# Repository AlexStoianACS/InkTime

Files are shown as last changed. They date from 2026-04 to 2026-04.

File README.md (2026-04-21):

## InkTime

Smartwatch ieftin si open source.

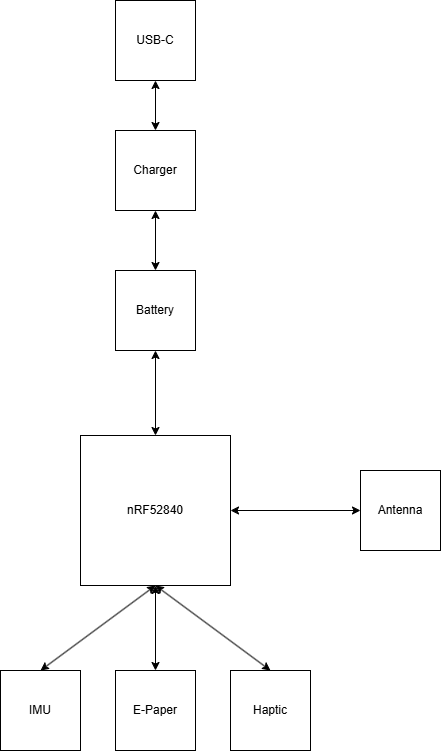
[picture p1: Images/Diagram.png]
Diagrama bloc


### Power Management

Charger LiPo: BQ25180

Regulator 3.3V: RT6160

Fuel gauge: MAX17048

#### Interfata

I2C (SDA/SCL bus comun)

Pini INT pentru evenimente (PMIC_INT, ALERT)

### Display (e-paper)

Conector FPC pentru display e-paper

Circuit de drive + PFET pentru power gating (VEPD)

#### Interfata

SPI:

SCK -> P0.02

MOSI -> P0.03

CS -> P0.05

Control:

DC -> P0.15

RST -> P0.16

BUSY -> P0.17

### Senzori

IMU (accelerometru): BMA421

#### Interfata

I2C:

SDA -> P0.06

SCL -> P0.07

### Haptic Feedback

DRV2605L

#### Interfata

I2C (bus comun)

Enable:

HAPTIC_EN -> P0.12

### Butoane

Up -> P0.13

Down -> P0.14

Enter -> P1.00

### Interfata
D+ -> USB DP (nRF52840)

D- -> USB DM (nRF52840)

VBUS -> detect pin

### Schematic

Schematicul l-am realizat pe o singura pagina.

Toate rezistentele sunt SMD, in capsula 0201. Toate condensatoarele sunt SMD, cele cu valori mai mici sau egale cu 100nF sunt in capsula 0201, cele cu valori mai mari de 100nF sunt 0402.

Am ignorat erorile de ERC de genul "Power pin X connected to Y" sau "Only one pin on net X".

### PCB

PCB-ul este de tip 2-layer si am facut rutarea pe ambele parti, in timp ce componentele sunt doar pe top.

Am plasat butoanele, usb-c connector si e-paper display connector pentru a se alinia cu marginile corespunzator.

Condensatoarele de decuplare (100nF) au fost plasate cat mai aproape de pinii de alimentare. De asemenea, cristalele au fost plasate cat mai aproape de MCU.

Am izolat antena de restul circuitului, nu am trasat rute pe top / bottom unde se afla si nu am facut "polygon pour" in acea zona. Pad-ul "2" a fost plasat in exterior.

Rutele au grosimea 0.3mm pentru semnalele de tip "POWER" si 0.15mm in rest. In anumite cazuri am scazut grosimea pentru a le putea strecura prin anumite locuri.

M-am ajutat de "escape routing" prin plasarea unui via direct pe pin / pad si inceperea rutarii direct pe bottom.

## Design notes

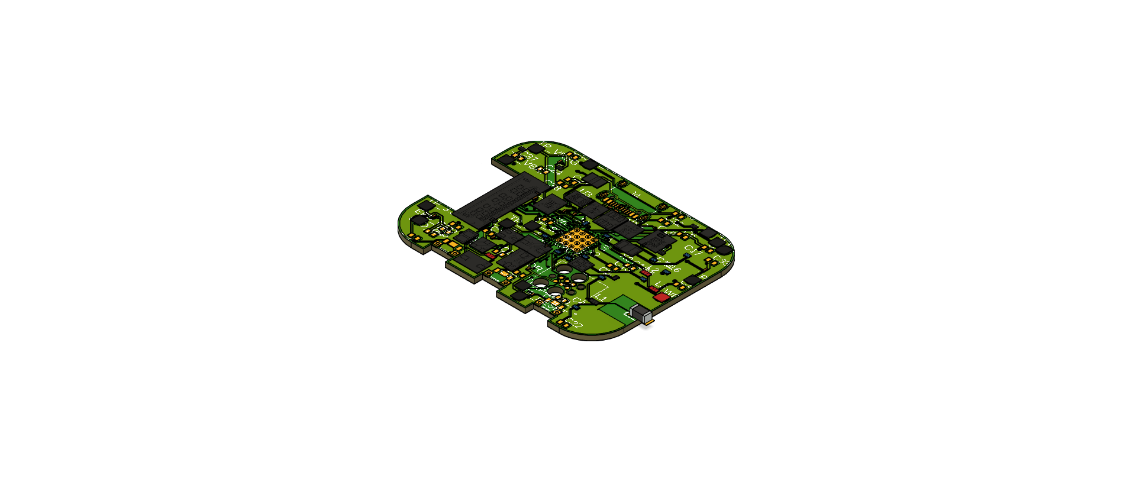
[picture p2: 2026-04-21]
Images/PCB.png

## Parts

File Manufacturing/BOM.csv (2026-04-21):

Reference Designators | Quantity | Description | Package | Value | Manufacturer | Manufacturer Part Number | Vendor | Vendor Part Number | Top/Bottom
 | 1 | Board | Board
ANT1 | 1 | Antennas 2.45GHz ANTENNA | 2450AT18B100E | 2450AT18B100E |  |  |  |  | Top
C1, C2, C17, C18 | 4 | Generic chip capacitor | NORDIC_NRF_3_RESC0201_L | 12pF |  |  |  |  | Top
C1-EP-DR, C24, C39 | 3 | CAPACITOR, European symbol | ESP32_C6_LIBRARY_1_ESP32_WROVER_EAGLE-LTSPICE_C0402 | 10uF |  |  |  |  | Top
C2-EP-DR, C6, C14, C20, C21, C43 | 6 | CAPACITOR, European symbol | ESP32_C6_LIBRARY_1_ESP32_WROVER_EAGLE-LTSPICE_C0402 | 4.7uF |  |  |  |  | Top
C3, C4 | 2 | Generic chip capacitor | NORDIC_NRF_3_RESC0201_L | 1pF |  |  |  |  | Top
C5, C7, C8, C12, C19 | 5 | Generic chip capacitor | NORDIC_NRF_3_RESC0201_L | 100nF |  |  |  |  | Top
C9 | 1 | Generic chip capacitor | NORDIC_NRF_3_RESC0201_L | 820pF |  |  |  |  | Top
C10, C13, C22 | 3 | CAPACITOR, European symbol | ESP32_C6_LIBRARY_1_ESP32_WROVER_EAGLE-LTSPICE_C0402 | N.C. |  |  |  |  | Top
C11 | 1 | Generic chip capacitor | NORDIC_NRF_3_RESC0201_L | 100pF |  |  |  |  | Top
C15 | 1 | CAPACITOR, European symbol | ESP32_C6_LIBRARY_1_ESP32_WROVER_EAGLE-LTSPICE_C0402 | 1.0uF |  |  |  |  | Top
C16 | 1 | Generic chip capacitor | NORDIC_NRF_3_RESC0201_L | 47nF |  |  |  |  | Top
C23, C27, C34, C42 | 4 | Check availability | CAPC0201X13N | 0.1uF |  |  |  |  | Top
C25, C33 | 2 | CAPACITOR, European symbol | ESP32_C6_LIBRARY_1_ESP32_WROVER_EAGLE-LTSPICE_C0402 | 22uF |  |  |  |  | Top
C29, C30, C31, C32, C37, C38 | 6 | CAPACITOR, European symbol | ESP32_C6_LIBRARY_1_ESP32_WROVER_EAGLE-LTSPICE_C0402 | 1uF |  |  |  |  | Top
D2, D4, D5 | 3 | ON SEMICONDUCTOR - MBR0530 - DIODE, SCHOTTKY, 0.5A, 30V, SOD-123 | SOD3716X135N | MBR0530 |  |  |  |  | Top
D3 | 1 | Low Cap. ESD Protection Auto SOT-23-6 STMicroelectronics USBLC6-2SC6Y, Dual Uni-Directional TVS Diode Array, 6-Pin SOT-23 | SOT95P280X145-6N | ESP32_C6_LIBRARY_3_USBLC6-2SC6Y |  |  |  |  | Top
EPD_C1, EPD_C2, EPD_C7, EPD_C8, EPD_C9, EPD_C10, EPD_C11, EPD_C12 | 8 | CAPACITOR, European symbol | ESP32_C6_LIBRARY_1_ESP32_WROVER_EAGLE-LTSPICE_C0402 | 1uF/50V |  |  |  |  | Top
EPD_C5 | 1 | Check availability | CAPC0201X13N | 0.1uF/50V |  |  |  |  | Top
EPD_C6 | 1 | CAPACITOR, European symbol | ESP32_C6_LIBRARY_1_ESP32_WROVER_EAGLE-LTSPICE_C0402 | 1uF/5OV |  |  |  |  | Top
IC1 | 1 | Charger IC Lithium Ion/Polymer, Lithium Iron Phosphate 8-DSBGA (1.6x1.1) | BQ25180YBGR_BGA8C40P2X4_100X155X50 | BQ25180YBGR_BQ25180YBGR |  |  |  |  | Top
IC2 | 1 | Haptic Driver for ERM/LRA with Built-In Library and Smart Loop Architecture | DRV2605YZFR_BGA9C50P3X3_144X144X62 | DRV2605YZFR_DRV2605YZFR |  |  |  |  | Top
IC3 | 1 | Accelerometers Triaxial low-g 12bit Acceleration Sensor | BMA423_BMA423 | BMA423 |  |  |  |  | Top
IC9 | 1 | Buck-Boost Regulator Positive Output Step-Up/Step-Down I2C DC-DC Controller IC 15-WL-CSP (BSC) (1.4x2.3) | RT6160AWSC_BGA15C40P3X5_140X230X60 | RT6160AWSC |  |  |  |  | Top
J1 | 1 | FFC & FPC Connectors 0.5mm FPC RA SMT Dual Contact 24Ckt | 503480-2400_5034802400 | 503480-2400_503480-2400 |  |  |  |  | Top
J2\ | 1 | CABLE ADAPTER 6 POS | TC2030-IDC_TC2030IDC | TC2030-IDC |  |  |  |  | Top
J4 | 1 | Check availability | KINGHELM_KH-TYPE-C-16P | KH-TYPE-C-16P |  |  |  |  | Top
L1 | 1 | Generic chip inductor | NORDIC_NRF_2_RESC0402_L | 3.9nH |  |  |  |  | Top
L2 | 1 | Generic chip inductor | NORDIC_NRF_2_RESC0402_L | 10uH |  |  |  |  | Top
L3 | 1 | Generic chip inductor | NORDIC_NRF_2_RESC0402_L | 15nH |  |  |  |  | Top
L5 | 1 | Generic chip inductor | NORDIC_NRF_2_RESC0402_L | 68uH |  |  |  |  | Top
L7 | 1 | SMD / SMT Inductors (Coils), L=0.47?H, L x W x T : | MLP2016SR47MT0S1_INDC2016X100N | FTC252012SR47MBCA |  |  |  |  | Top
Q1 | 1 | P-channel MOSFETs | ESP32_WROVER_SPARKFUN-DISCRETESEMI_SOT23-3 | 20V/4.2A/52mΩ/1.4W |  |  |  |  | Top
Q3 | 1 | MOSFET N-Ch 30V 1.5A TrenchFET SC70 Vishay Si1308EDL-T1-GE3 N-channel MOSFET Transistor, 1.5 A, 30 V, 3-Pin SC-70 | SOT65P210X110-3N | SI1308EDL-T1-GE3 |  |  |  |  | Top
R_PWR_EPD, R2_EP_DR, R5, R7, R8, R9 | 6 | 7.68k 0201 Thin Film Surface Mount Fixed Resistor +/-0.5% 0.031W CPF0201D7K68C1 | CPF0201D7K68C1_0201 | 10K |  |  |  |  | Top
R_TYPE_SEL | 1 | 7.68k 0201 Thin Film Surface Mount Fixed Resistor +/-0.5% 0.031W CPF0201D7K68C1 | CPF0201D7K68C1_0201 | 2.2 |  |  |  |  | Top
R1_EP_DR | 1 | 7.68k 0201 Thin Film Surface Mount Fixed Resistor +/-0.5% 0.031W CPF0201D7K68C1 | CPF0201D7K68C1_0201 | 0.47 |  |  |  |  | Top
R1_USB, R2_USB | 2 | 7.68k 0201 Thin Film Surface Mount Fixed Resistor +/-0.5% 0.031W CPF0201D7K68C1 | CPF0201D7K68C1_0201 | 5K1 |  |  |  |  | Top
R2, R3, R4 | 3 | 7.68k 0201 Thin Film Surface Mount Fixed Resistor +/-0.5% 0.031W CPF0201D7K68C1 | CPF0201D7K68C1_0201 | 0 |  |  |  |  | Top
R17, R18 | 2 | 7.68k 0201 Thin Film Surface Mount Fixed Resistor +/-0.5% 0.031W CPF0201D7K68C1 | CPF0201D7K68C1_0201 | 3K3 |  |  |  |  | Top
SJ1 | 1 | SMD solder JUMPER | JUMPER_SJ | SJ |  |  |  |  | Top
SW_DN, SW_ENT, SW_UP | 3 |  | SW_EVP-AKE31A_PAN | 2025-10-22_07-23-44_LIBRARY_EVP-AKE31ASW_EVP-AKE31A_PAN |  |  |  |  | Top
TP_3.3V, TP_3V3, TP_BAT_GND, TP_GND, TP_RESET, TP_SCL, TP_SDA, TP_SWDIO, TP_SWO, TP_VBAT, TP_VREG, TP1, TP2, WP_SWDCLK | 14 | Test pad | HECTOR_WATCH_1_TP20R | HECTOR_WATCH_1_TPTP20R |  |  |  |  | Top
U1 | 1 | nRF52840 | NORDIC_NRF_4_AQFN50P700X700X85_HS-74N | NRF52840_QF |  |  |  |  | Top
U3 | 1 | Check availability | SON50P200X200X80-9N | ESP32_C6_LIBRARY_MAX17048G+T10 |  |  |  |  | Top
X1 | 1 |  | NORDIC_NRF_BT-XTAL_2016_N | 32MHz |  |  |  |  | Top
X2 | 1 |  | NORDIC_NRF_1_XTAL_3215_N | 32.768kHz |  |  |  |  | Top

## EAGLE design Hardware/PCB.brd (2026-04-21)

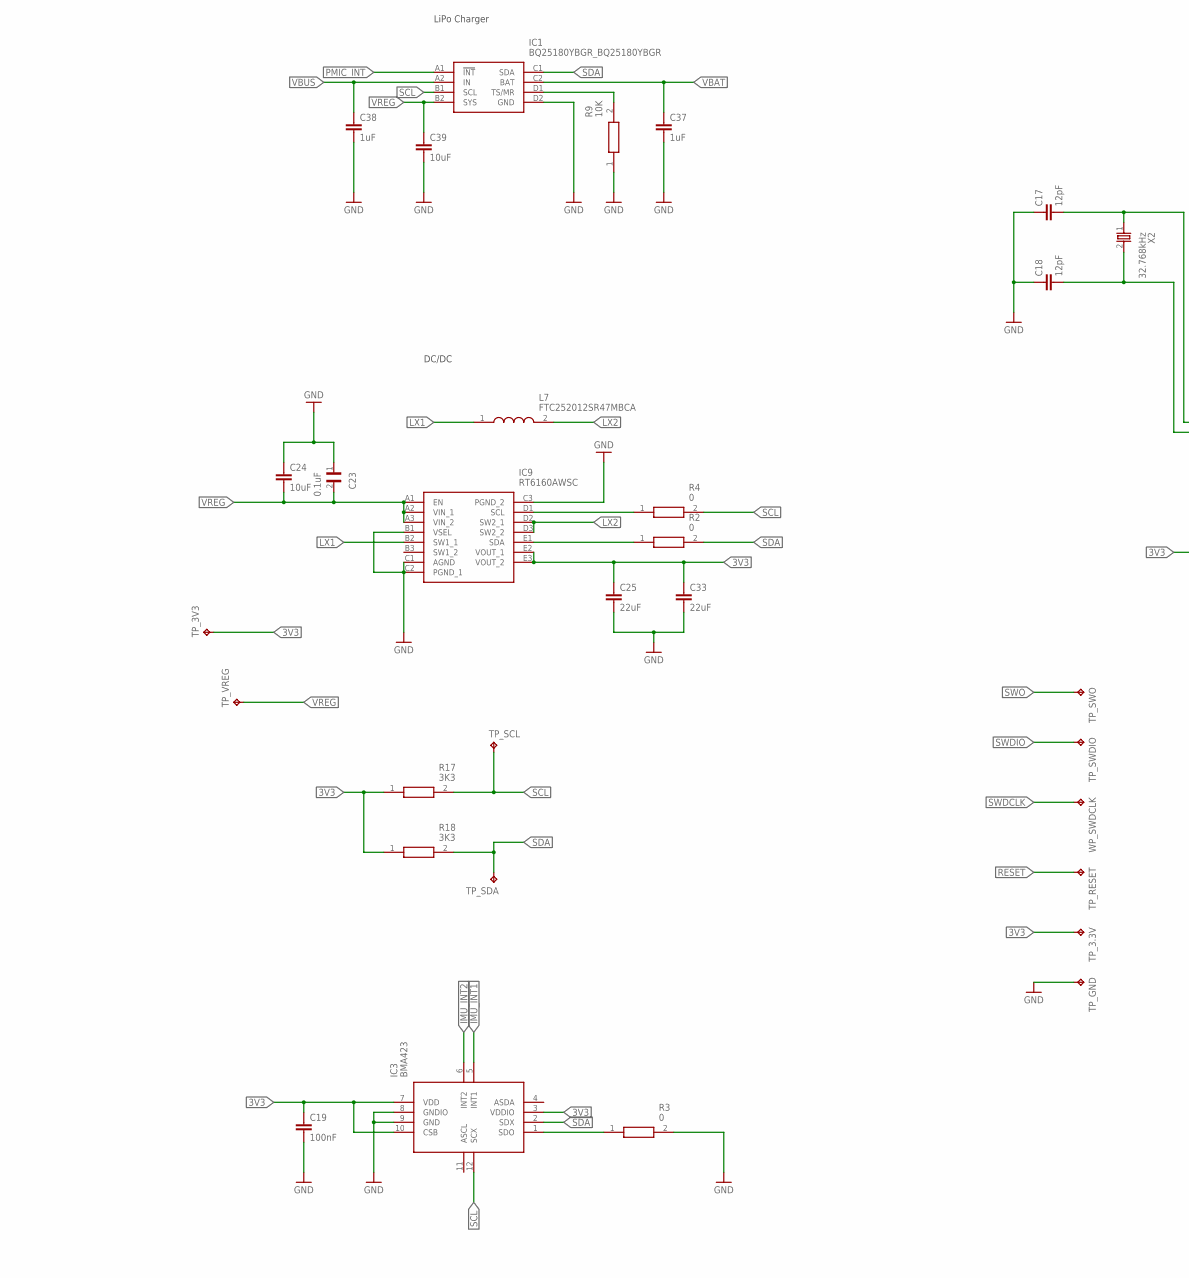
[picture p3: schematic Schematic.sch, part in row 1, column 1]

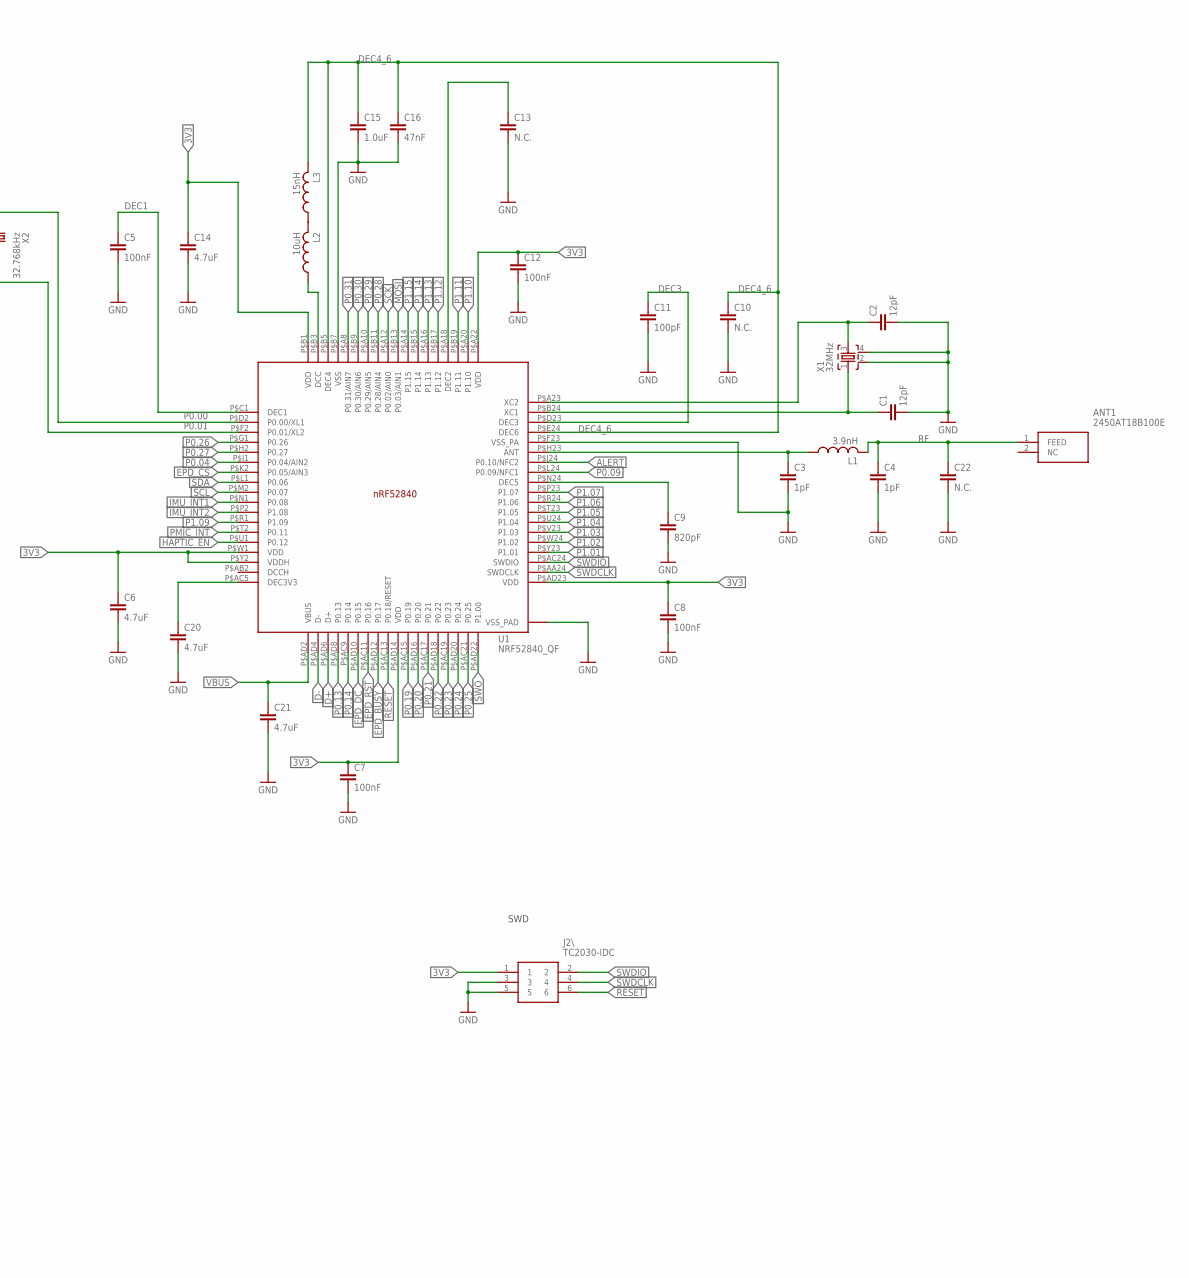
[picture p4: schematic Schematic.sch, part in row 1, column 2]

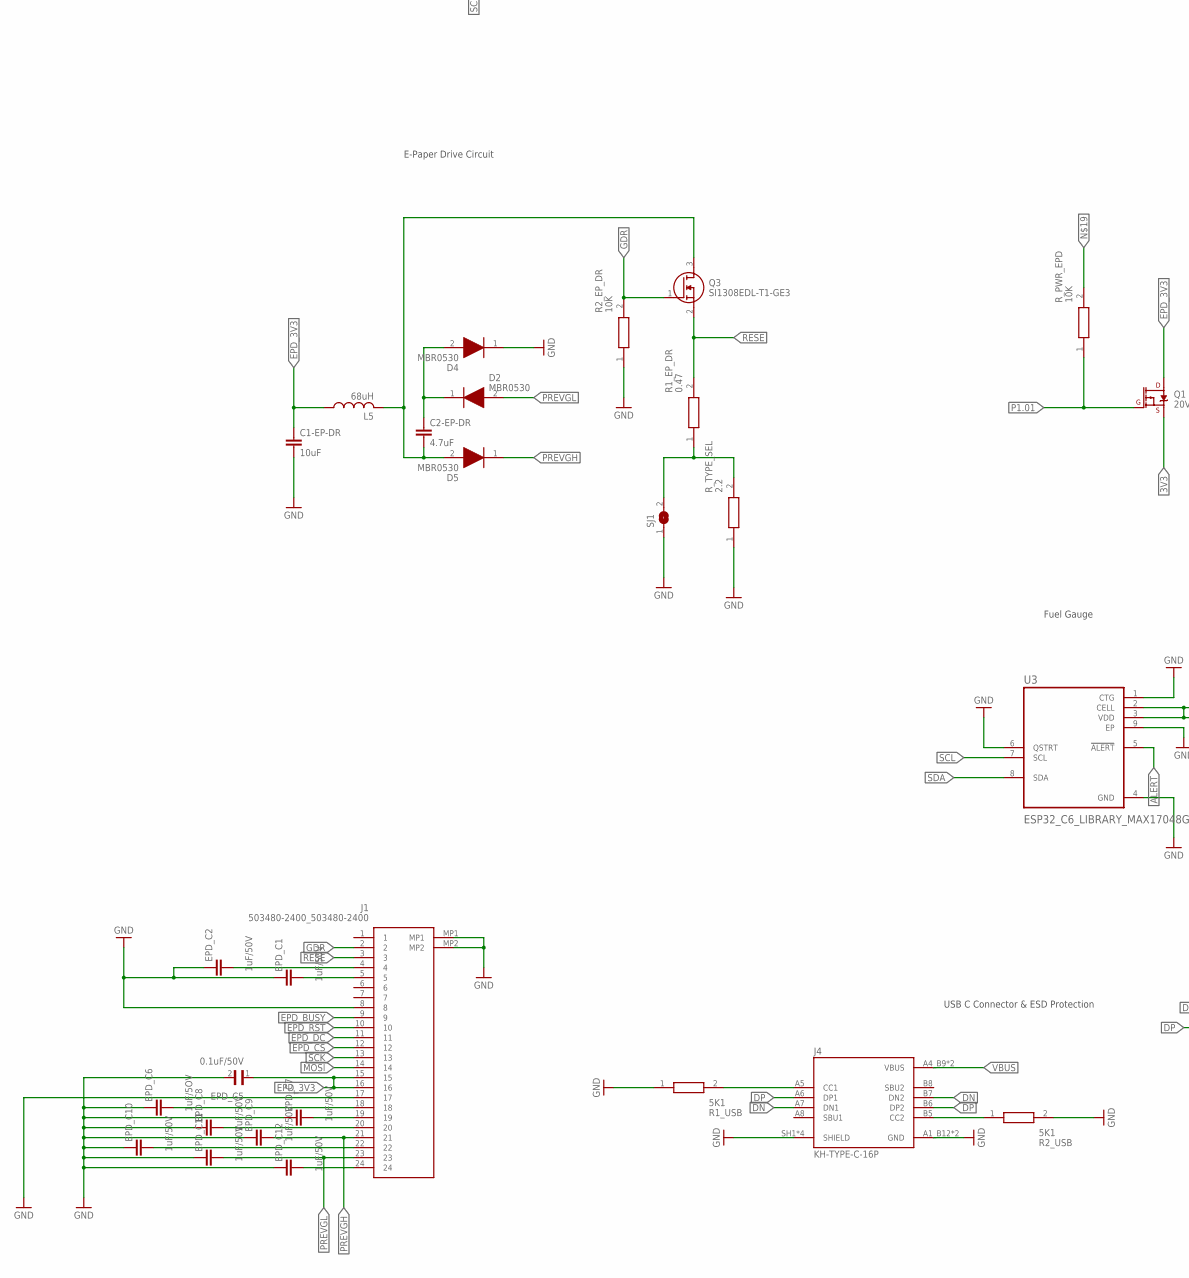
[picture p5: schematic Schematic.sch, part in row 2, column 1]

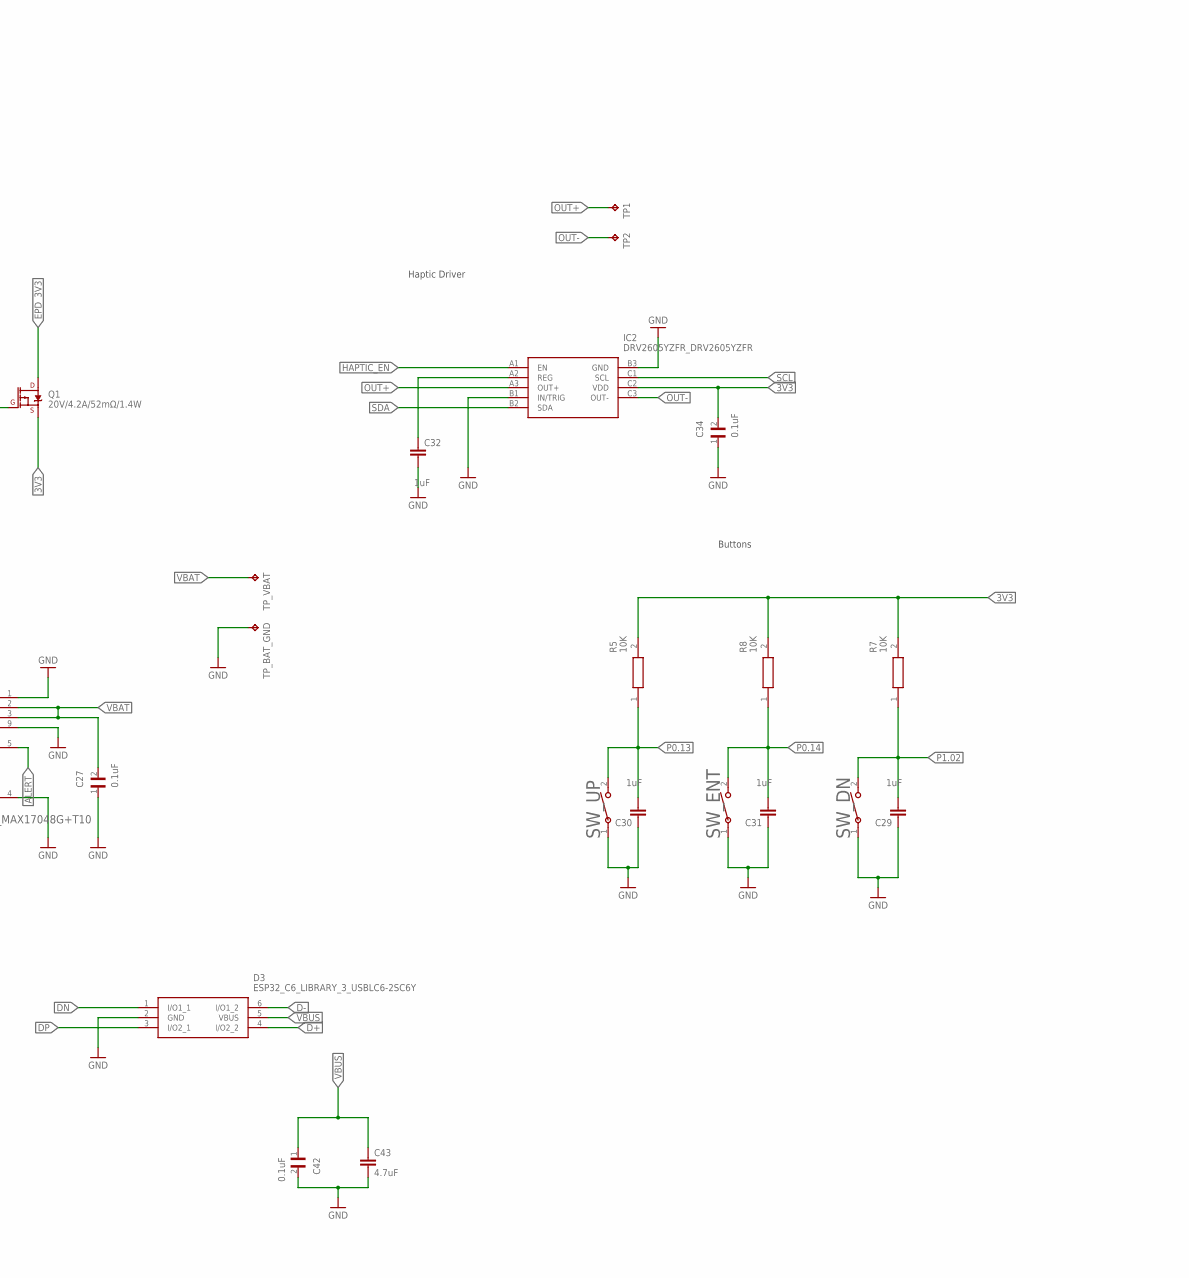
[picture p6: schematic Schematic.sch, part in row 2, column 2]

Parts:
ANT1: 2450AT18B100E; 2450AT18B100E_ANTC3216X140N
C1, C2, C17, C18: 12pF; NORDIC_NRF_3_RESC0201_L
C1-EP-DR, C24, C39: 10uF; ESP32_C6_LIBRARY_1_ESP32_WROVER_EAGLE-LTSPICE_C0402
C2-EP-DR, C6, C14, C20, C21, C43: 4.7uF; ESP32_C6_LIBRARY_1_ESP32_WROVER_EAGLE-LTSPICE_C0402
C3, C4: 1pF; NORDIC_NRF_3_RESC0201_L
C5, C7, C8, C12, C19: 100nF; NORDIC_NRF_3_RESC0201_L
C9: 820pF; NORDIC_NRF_3_RESC0201_L
C10, C13, C22: N.C.; ESP32_C6_LIBRARY_1_ESP32_WROVER_EAGLE-LTSPICE_C0402
C11: 100pF; NORDIC_NRF_3_RESC0201_L
C15: 1.0uF; ESP32_C6_LIBRARY_1_ESP32_WROVER_EAGLE-LTSPICE_C0402
C16: 47nF; NORDIC_NRF_3_RESC0201_L
C23, C27, C34, C42: 0.1uF; GRM011R60J152KE01L_2_CAPC0201X13N
C25, C33: 22uF; ESP32_C6_LIBRARY_1_ESP32_WROVER_EAGLE-LTSPICE_C0402
C29, C30, C31, C32, C37, C38: 1uF; ESP32_C6_LIBRARY_1_ESP32_WROVER_EAGLE-LTSPICE_C0402
D2, D4, D5: MBR0530; ESP32_C6_LIBRARY_5_SOD3716X135N
D3: ESP32_C6_LIBRARY_3_USBLC6-2SC6Y; ESP32_C6_LIBRARY_3_SOT95P280X145-6N
EPD_C1, EPD_C2, EPD_C7, EPD_C8, EPD_C9, EPD_C10, EPD_C11, EPD_C12: 1uF/50V; ESP32_C6_LIBRARY_1_ESP32_WROVER_EAGLE-LTSPICE_C0402
EPD_C5: 0.1uF/50V; GRM011R60J152KE01L_2_CAPC0201X13N
EPD_C6: 1uF/5OV; ESP32_C6_LIBRARY_1_ESP32_WROVER_EAGLE-LTSPICE_C0402
IC1: BQ25180YBGR_BQ25180YBGR; BQ25180YBGR_BGA8C40P2X4_100X155X50
IC2: DRV2605YZFR_DRV2605YZFR; DRV2605YZFR_BGA9C50P3X3_144X144X62
IC3: BMA423; BMA423_BMA423
IC9: RT6160AWSC; RT6160AWSC_BGA15C40P3X5_140X230X60
J1: 503480-2400_503480-2400; 503480-2400_5034802400
J2\: TC2030-IDC; TC2030-IDC_TC2030IDC
J4: KH-TYPE-C-16P; KH-TYPE-C-16P_KINGHELM_KH-TYPE-C-16P
L1: 3.9nH; NORDIC_NRF_2_RESC0402_L
L2: 10uH; NORDIC_NRF_2_RESC0402_L
L3: 15nH; NORDIC_NRF_2_RESC0402_L
L5: 68uH; NORDIC_NRF_2_RESC0402_L
L7: FTC252012SR47MBCA; MLP2016SR47MT0S1_INDC2016X100N
Q1: 20V/4.2A/52mΩ/1.4W; ESP32_C6_LIBRARY_4_ESP32_C6_LIBRARY_4_ESP32_C6_LIBRARY_4_ES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
Q3: SI1308EDL-T1-GE3; ESP32_C6_LIBRARY_6_SOT65P210X110-3N
R1_EP_DR: 0.47; CPF0201D7K68C1_0201
R1_USB, R2_USB: 5K1; CPF0201D7K68C1_0201
R2, R3, R4: 0; CPF0201D7K68C1_0201
R2_EP_DR, R5, R7, R8, R9: 10K; CPF0201D7K68C1_0201
R17, R18: 3K3; CPF0201D7K68C1_0201
R_PWR_EPD: 10K; CPF0201D7K68C1_0201
R_TYPE_SEL: 2.2; CPF0201D7K68C1_0201
SJ1: SJ; ESP32_C6_LIBRARY_7_JUMPER_SJ
SW_DN: 2025-10-22_07-23-44_LIBRARY_EVP-AKE31ASW_EVP-AKE3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; 2025-10-22_07-23-44_LIBRARY_SW_EVP-AKE31A_PAN
SW_ENT: 2025-10-22_07-23-44_LIBRARY_EVP-AKE31ASW_EVP-AKE3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; 2025-10-22_07-23-44_LIBRARY_SW_EVP-AKE31A_PAN
SW_UP: 2025-10-22_07-23-44_LIBRARY_EVP-AKE31ASW_EVP-AKE3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; 2025-10-22_07-23-44_LIBRARY_SW_EVP-AKE31A_PAN
TP1, TP2: HECTOR_WATCH_1_TPTP20R; HECTOR_WATCH_1_TP20R
TP_3.3V, TP_3V3: HECTOR_WATCH_1_TPTP20R; HECTOR_WATCH_1_TP20R
TP_BAT_GND: HECTOR_WATCH_1_TPTP20R; HECTOR_WATCH_1_TP20R
TP_GND: HECTOR_WATCH_1_TPTP20R; HECTOR_WATCH_1_TP20R
TP_RESET: HECTOR_WATCH_1_TPTP20R; HECTOR_WATCH_1_TP20R
TP_SCL: HECTOR_WATCH_1_TPTP20R; HECTOR_WATCH_1_TP20R
TP_SDA: HECTOR_WATCH_1_TPTP20R; HECTOR_WATCH_1_TP20R
TP_SWDIO: HECTOR_WATCH_1_TPTP20R; HECTOR_WATCH_1_TP20R
TP_SWO: HECTOR_WATCH_1_TPTP20R; HECTOR_WATCH_1_TP20R
TP_VBAT: HECTOR_WATCH_1_TPTP20R; HECTOR_WATCH_1_TP20R
TP_VREG: HECTOR_WATCH_1_TPTP20R; HECTOR_WATCH_1_TP20R
U1: NRF52840_QF; NORDIC_NRF_4_AQFN50P700X700X85_HS-74N
U3: ESP32_C6_LIBRARY_MAX17048G+T10; ESP32_C6_LIBRARY_SON50P200X200X80-9N
WP_SWDCLK: HECTOR_WATCH_1_TPTP20R; HECTOR_WATCH_1_TP20R
X1: 32MHz; NORDIC_NRF_BT-XTAL_2016_N
X2: 32.768kHz; NORDIC_NRF_1_XTAL_3215_N

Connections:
3V3: C6.1, C7.1, C8.1, C12.1, C14.1, C19.1, C25.1, C33.1, C34.2, IC2.C2 (VDD), IC3.3 (VDDIO), IC3.7 (VDD), IC3.10 (CSB), IC9.E2 (VOUT_1), IC9.E3 (VOUT_2), J2\.1, Q1.2 (S), R5.2, R7.2, R8.2, R17.1, R18.1, TP_3.3V.TP, TP_3V3.TP, U1.P$A22 (VDD), U1.P$AD14 (VDD), U1.P$AD23 (VDD), U1.P$B1 (VDD), U1.P$W1 (VDD), U1.P$Y2 (VDDH)
ALERT: U1.P$J24 (P0.10/NFC2), U3.5 (!ALERT)
D+: D3.4 (I/O2_2), U1.P$AD6 (D+)
D-: D3.6 (I/O1_2), U1.P$AD4 (D-)
DEC1: C5.1, U1.P$C1 (DEC1)
DEC3: C11.1, U1.P$D23 (DEC3)
DEC4_6: C10.1, C15.1, C16.1, L3.2, U1.P$B5 (DEC4), U1.P$E24 (DEC6)
DN: D3.1 (I/O1_1), J4.A7 (DN1), J4.B7 (DN2)
DP: D3.3 (I/O2_1), J4.A6 (DP1), J4.B6 (DP2)
EPD_3V3: C1-EP-DR.1, EPD_C5.1, J1.15, J1.16, L5.1, Q1.3 (D)
EPD_BUSY: J1.9, U1.P$AD12 (P0.17)
EPD_CS: J1.12, U1.P$K2 (P0.05/AIN3)
EPD_DC: J1.11, U1.P$AD10 (P0.15)
EPD_RST: J1.10, U1.P$AC11 (P0.16)
GDR: J1.2, Q3.1 (G), R2_EP_DR.2
GND: C1.2, C1-EP-DR.2, C2.2, C3.2, C4.2, C5.2, C6.2, C7.2, C8.2, C9.2, C10.2, C11.2, C12.2, C13.2, C14.2, C15.2, C16.2, C17.1, C18.1, C19.2, C20.2, C21.2, C22.2, C23.1, C24.1, C25.2, C27.1, C29.1, C30.1, C31.1, C32.2, C33.2, C34.1, C37.2, C38.2, C39.2, C42.2, C43.2, D3.2 (GND), D4.1 (K), EPD_C1.1, EPD_C2.1, EPD_C5.2, EPD_C6.1, EPD_C7.1, EPD_C8.1, EPD_C9.1, EPD_C10.1, EPD_C11.1, EPD_C12.1, IC1.D2 (GND), IC2.B1 (IN/TRIG), IC2.B3 (GND), IC3.8 (GNDIO), IC3.9 (GND), IC9.B1 (VSEL), IC9.C1 (AGND), IC9.C2 (PGND_1), IC9.C3 (PGND_2), J1.8, J1.17, J1.MP1, J1.MP2, J2\.3, J2\.5, J4.A1_B12 (GND), J4.A12_B1 (GND), J4.SH1 (SHIELD), J4.SH2 (SHIELD), J4.SH3 (SHIELD), J4.SH4 (SHIELD), R1_USB.1, R2_EP_DR.1, R2_USB.2, R3.2, R9.1, R_TYPE_SEL.1, SJ1.1, SW_DN.1, SW_ENT.1, SW_UP.1, TP_BAT_GND.TP, TP_GND.TP, U1.P$74 (VSS_PAD), U1.P$75 (VSS_PAD), U1.P$76 (VSS_PAD), U1.P$77 (VSS_PAD), U1.P$78 (VSS_PAD), U1.P$79 (VSS_PAD), U1.P$80 (VSS_PAD), U1.P$81 (VSS_PAD), U1.P$82 (VSS_PAD), U1.P$83 (VSS_PAD), U1.P$84 (VSS_PAD), U1.P$85 (VSS_PAD), U1.P$86 (VSS_PAD), U1.P$87 (VSS_PAD), U1.P$88 (VSS_PAD), U1.P$89 (VSS_PAD), U1.P$90 (VSS_PAD), U1.P$B7 (VSS), U1.P$F23 (VSS_PA), U3.1 (CTG), U3.4 (GND), U3.6 (QSTRT), U3.9 (EP), X1.2, X1.4
HAPTIC_EN: IC2.A1 (EN), U1.P$U1 (P0.12)
IMU_INT1: IC3.5 (INT1), U1.P$N1 (P0.08)
IMU_INT2: IC3.6 (INT2), U1.P$P2 (P1.08)
LX1: IC9.B2 (SW1_1), L7.1
LX2: IC9.D2 (SW2_1), IC9.D3 (SW2_2), L7.2
MOSI: J1.14, U1.P$B13 (P0.03/AIN1)
unnamed: J4.A5 (CC1), R1_USB.2
unnamed: C2-EP-DR.2, D5.2 (A), L5.2, Q3.3 (D)
unnamed: L2.2, L3.1
unnamed: IC3.1 (SDO), R3.1
unnamed: C2.1, U1.P$A23 (XC2), X1.3
unnamed: IC1.D1 (TS/MR), R9.2
unnamed: L2.1, U1.P$B3 (DCC)
unnamed: IC9.E1 (SDA), R2.1
unnamed: C1.1, U1.P$B24 (XC1), X1.1
unnamed: IC9.D1 (SCL), R4.1
unnamed: C13.1, U1.P$A18 (DEC2)
unnamed: C3.1, L1.1, U1.P$H23 (ANT)
unnamed: C20.1, U1.P$AC5 (DEC3V3)
unnamed: C2-EP-DR.1, D2.1 (K), D4.2 (A)
unnamed: C32.1, IC2.A2 (REG)
unnamed: C9.1, U1.P$N24 (DEC5)
unnamed: R1_EP_DR.1, R_TYPE_SEL.2, SJ1.2
unnamed: EPD_C2.2, J1.4
unnamed: EPD_C1.2, J1.5
unnamed: J4.B5 (CC2), R2_USB.1
unnamed: EPD_C12.2, J1.24
unnamed: EPD_C10.2, J1.22
unnamed: EPD_C8.2, J1.20
unnamed: EPD_C7.2, J1.19
unnamed: EPD_C6.2, J1.18
OUT+: IC2.A3 (OUT+), TP1.TP
OUT-: IC2.C3 (OUT-), TP2.TP
P0.00: C17.2, U1.P$D2 (P0.00/XL1), X2.1
P0.01: C18.2, U1.P$F2 (P0.01/XL2), X2.2
P0.04: U1.P$J1 (P0.04/AIN2)
P0.09: U1.P$L24 (P0.09/NFC1)
P0.13: C30.2, R5.1, SW_UP.2, U1.P$AD8 (P0.13)
P0.14: C31.2, R8.1, SW_ENT.2, U1.P$AC9 (P0.14)
P0.19: U1.P$AC15 (P0.19)
P0.20: U1.P$AD16 (P0.20)
P0.21: U1.P$AC17 (P0.21)
P0.22: U1.P$AD18 (P0.22)
P0.23: U1.P$AC19 (P0.23)
P0.24: U1.P$AD20 (P0.24)
P0.25: U1.P$AC21 (P0.25)
P0.26: U1.P$G1 (P0.26)
P0.27: U1.P$H2 (P0.27)
P0.28: U1.P$B11 (P0.28/AIN4)
P0.29: U1.P$A10 (P0.29/AIN5)
P0.30: U1.P$B9 (P0.30/AIN6)
P0.31: U1.P$A8 (P0.31/AIN7)
P1.01: Q1.1 (G), R_PWR_EPD.1, U1.P$Y23 (P1.01)
P1.02: C29.2, R7.1, SW_DN.2, U1.P$W24 (P1.02)
P1.03: U1.P$V23 (P1.03)
P1.04: U1.P$U24 (P1.04)
P1.05: U1.P$T23 (P1.05)
P1.06: U1.P$R24 (P1.06)
P1.07: U1.P$P23 (P1.07)
P1.09: U1.P$R1 (P1.09)
P1.10: U1.P$A20 (P1.10)
P1.11: U1.P$B19 (P1.11)
P1.12: U1.P$B17 (P1.12)
P1.13: U1.P$A16 (P1.13)
P1.14: U1.P$B15 (P1.14)
P1.15: U1.P$A14 (P1.15)
PMIC_INT: IC1.A1 (!INT), U1.P$T2 (P0.11)
PREVGH: D5.1 (K), EPD_C9.2, J1.21
PREVGL: D2.2 (A), EPD_C11.2, J1.23
RESE: J1.3, Q3.2 (S), R1_EP_DR.2
RESET: J2\.6, TP_RESET.TP, U1.P$AC13 (P0.18/RESET)
RF: ANT1.1 (FEED), C4.1, C22.1, L1.2
SCK: J1.13, U1.P$A12 (P0.02/AIN0)
SCL: IC1.B1 (SCL), IC2.C1 (SCL), IC3.12 (SCX), R4.2, R17.2, TP_SCL.TP, U1.P$M2 (P0.07), U3.7 (SCL)
SDA: IC1.C1 (SDA), IC2.B2 (SDA), IC3.2 (SDX), R2.2, R18.2, TP_SDA.TP, U1.P$L1 (P0.06), U3.8 (SDA)
SWDCLK: J2\.4, U1.P$AA24 (SWDCLK), WP_SWDCLK.TP
SWDIO: J2\.2, TP_SWDIO.TP, U1.P$AC24 (SWDIO)
SWO: TP_SWO.TP, U1.P$AD22 (P1.00)
VBAT: C27.2, C37.1, IC1.C2 (BAT), TP_VBAT.TP, U3.2 (CELL), U3.3 (VDD)
VBUS: C21.1, C38.1, C42.1, C43.1, D3.5 (VBUS), IC1.A2 (IN), J4.A4_B9 (VBUS), J4.A9_B4 (VBUS), U1.P$AD2 (VBUS)
VREG: C23.2, C24.2, C39.1, IC1.B2 (SYS), IC9.A1 (EN), IC9.A2 (VIN_1), IC9.A3 (VIN_2), TP_VREG.TP

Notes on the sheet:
LiPo Charger
DC/DC
SWD
E-Paper Drive Circuit
Haptic Driver
Fuel Gauge
Buttons
USB C Connector & ESD Protection

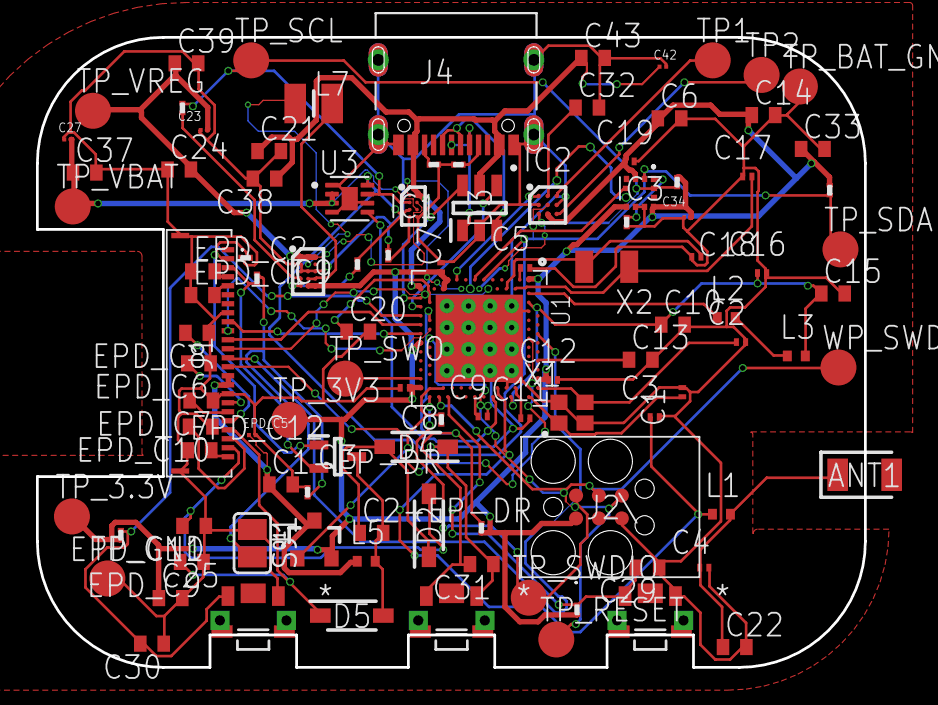
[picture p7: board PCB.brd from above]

Board: 2 copper layers, 46.0 x 35.0 mm, 105 parts (0 on the bottom side), 70 nets.

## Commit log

2026-04-10 Engineering Validation (EVT)
    [Electronics Design.csv, PCB.brd, Schematic.sch]
2026-04-21 Design Validation (DVT)
    [BOM.csv, Electronics Design.csv, PCB.brd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]

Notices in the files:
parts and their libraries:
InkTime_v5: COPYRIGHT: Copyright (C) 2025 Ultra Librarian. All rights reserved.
